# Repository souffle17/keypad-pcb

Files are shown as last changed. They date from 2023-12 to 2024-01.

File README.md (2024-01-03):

# keypad-pcb      

A simple 2x3 mechanical keypad.       

Case parts are designed for CNC machining, stacked and screwed together. Firmware uses QMK.       

### Resources:
- https://guide.zykrah.me/
- https://www.masterzen.fr/2020/05/03/designing-a-keyboard-part-1/
- https://wiki.ai03.com/books/pcb-design/chapter/pcb-designer-guide

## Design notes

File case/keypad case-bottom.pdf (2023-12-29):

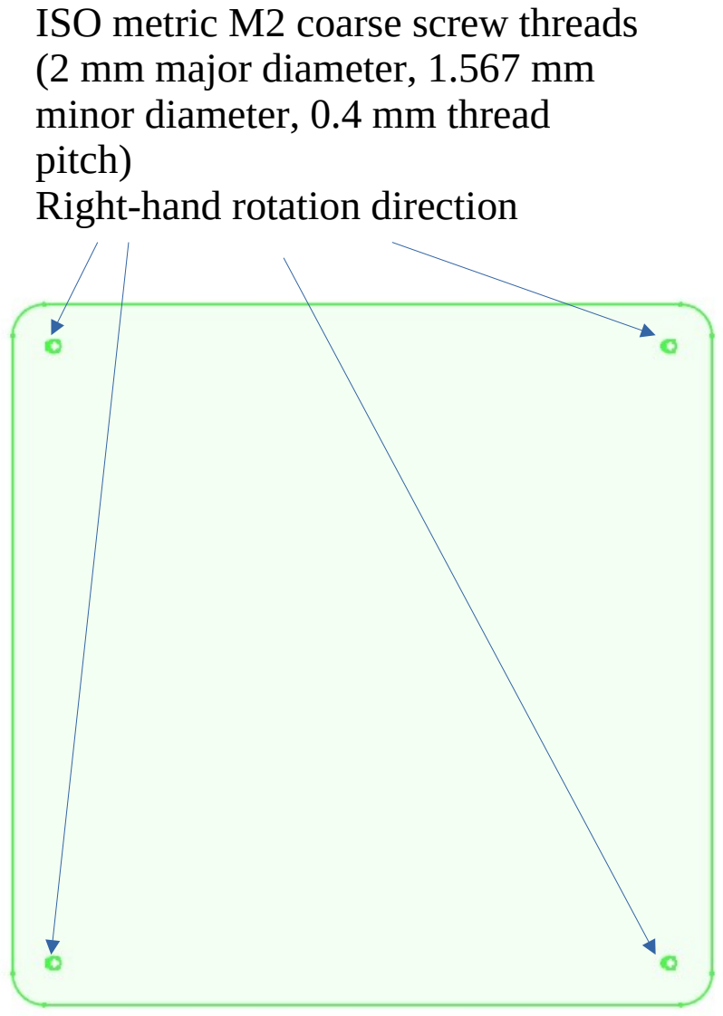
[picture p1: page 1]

ISO metric M2 coarse screw threads (2 mm major diameter, 1.567 mm minor diameter, 0.4 mm thread pitch)
Right-hand rotation direction

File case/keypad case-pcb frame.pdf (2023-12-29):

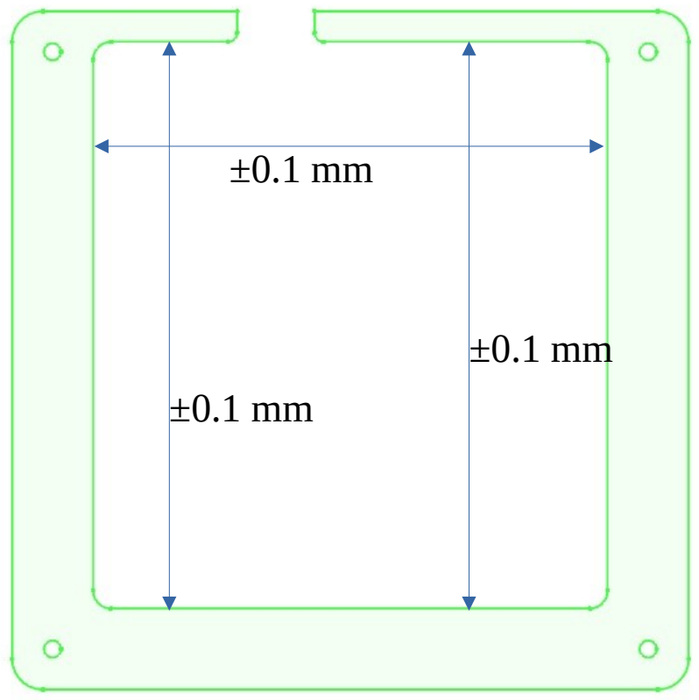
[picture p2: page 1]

±0.1 mm

±0.1 mm

±0.1 mm

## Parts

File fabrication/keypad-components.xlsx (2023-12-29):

Comment | Designator | Footprint | JLCPCB Part #（optional）
D | D5,D2,D6,D4,D3,D7 | SOD-123 | C77978
5.1k | R7,R8 | 0805 | C84375
ATmega32U4-A | U1 | TQFP-44 | C44854
RESET | SW0 | SKQG | C115351
10k | R4,R1 | 0805 | C84376
HRO-TYPE-C-31-M-12 | USB1 | HRO-TYPE-C-31-M-12 | C165948
0.1u | C2,C3,C4 | 0805 | C1711
1u | C1 | 0805 | C116352
22p | C6,C7 | 0805 | C1804
22 | R2,R3 | 0805 | C844832
PRTR5V0U2X | D1 | SOT143B | C12333
10u | C5 | 0805 | C95841
500m | F1 | 1206 | C70069
XTAL | Y1 | 3225 | C255909

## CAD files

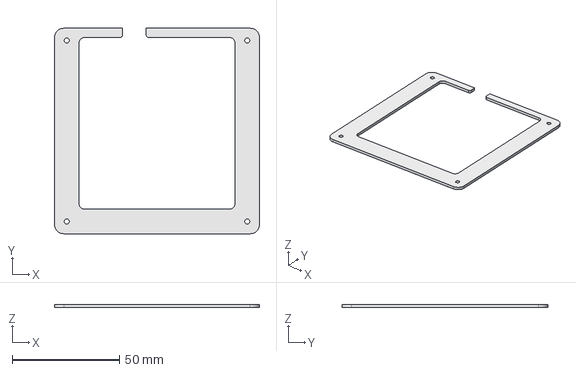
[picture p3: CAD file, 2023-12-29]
case/keypad case-pcb frame.step
95.5 x 95.7 x 1.60 mm

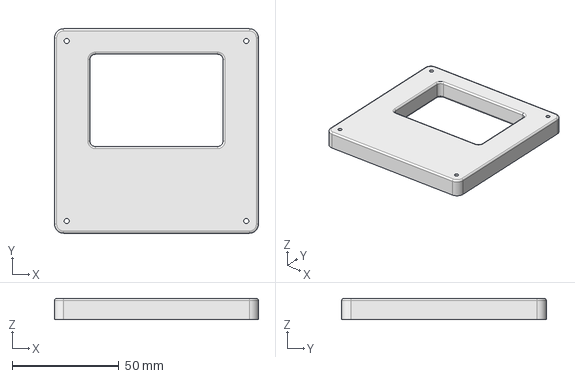
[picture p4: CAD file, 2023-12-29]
case/keypad case-top cover.step
95.5 x 95.7 x 10.0 mm

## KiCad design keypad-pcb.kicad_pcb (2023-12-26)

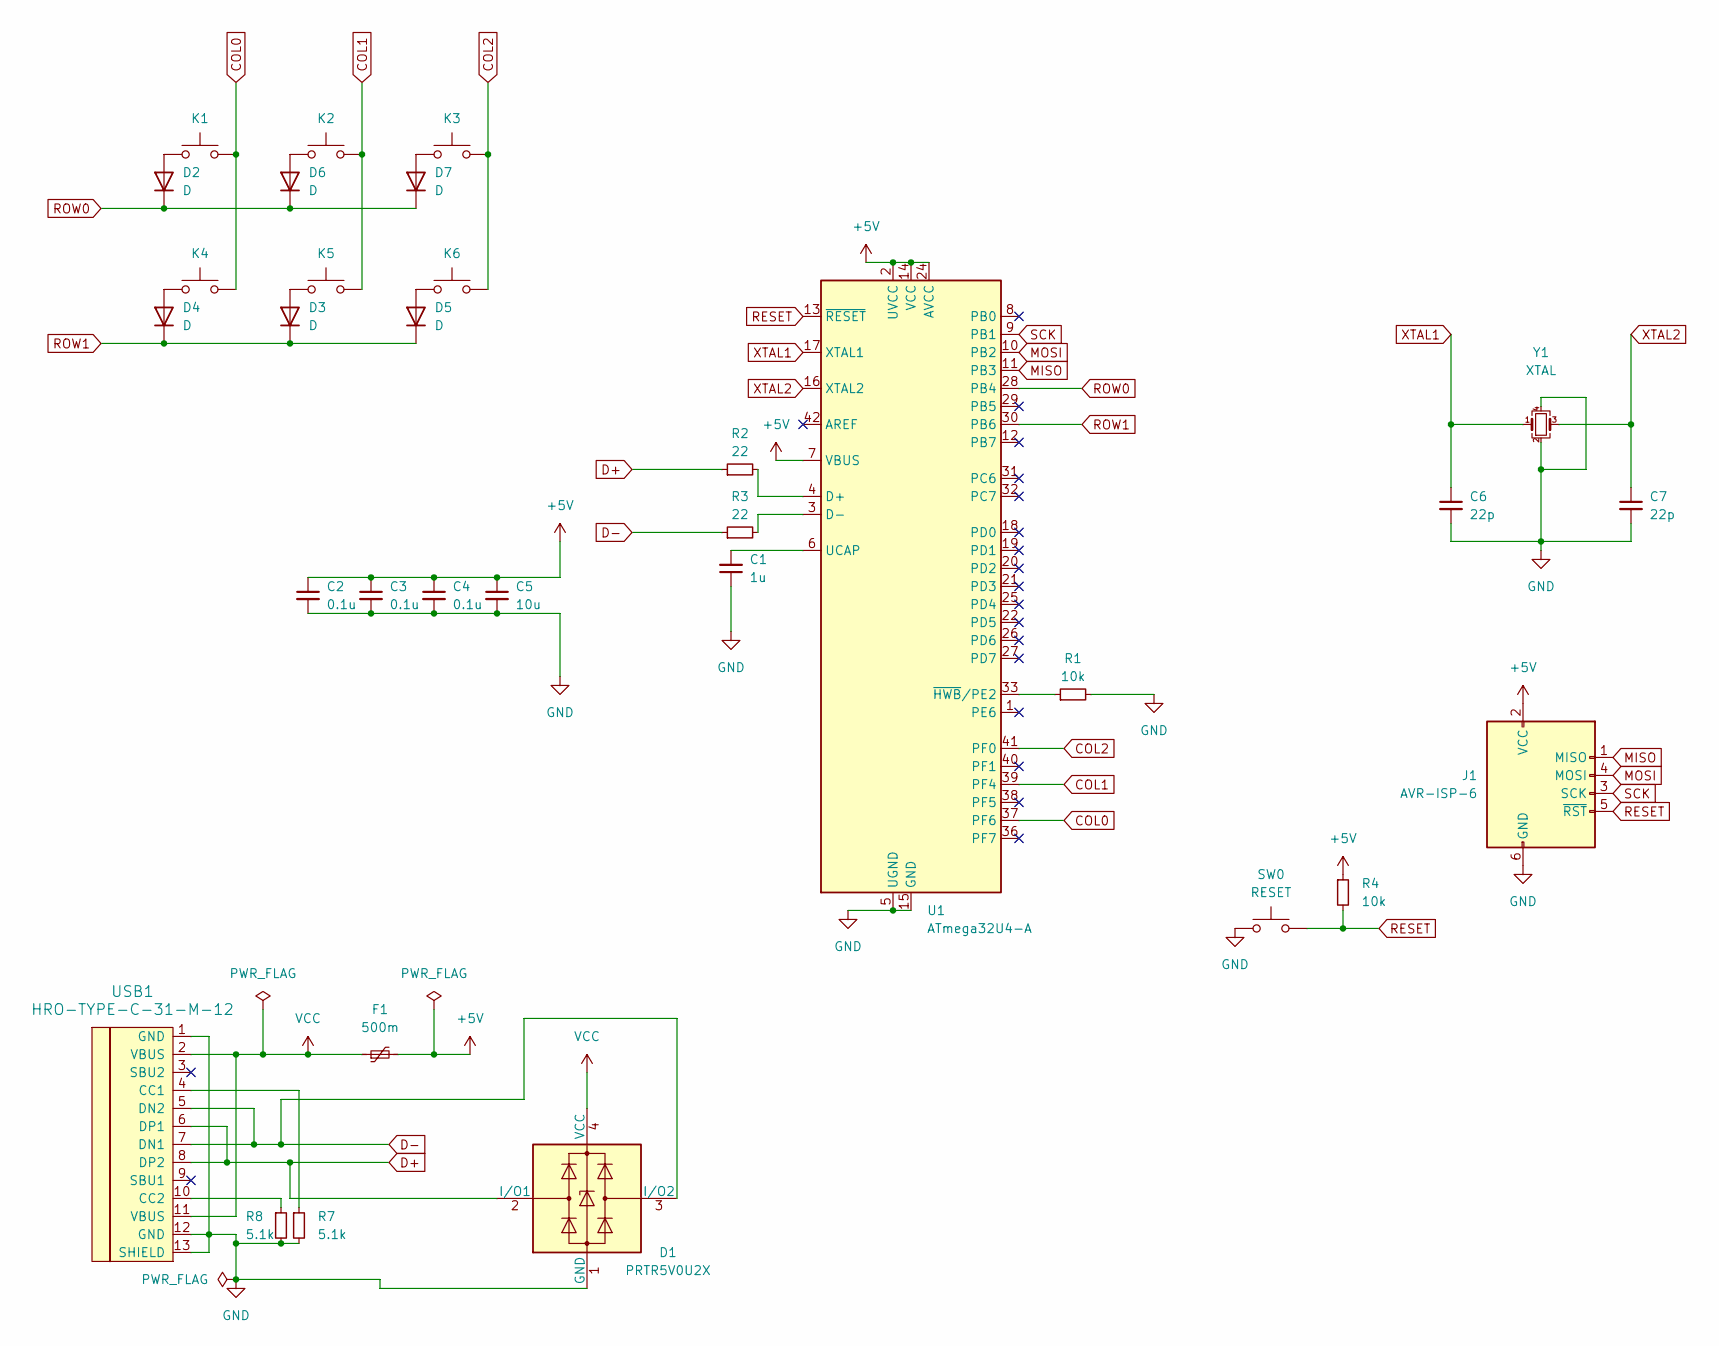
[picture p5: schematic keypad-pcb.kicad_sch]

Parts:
C1: 1u; C_0805_2012Metric
C2, C3, C4: 0.1u; C_0805_2012Metric
C5: 10u; C_0805_2012Metric
C6, C7: 22p; C_0805_2012Metric
D1: PRTR5V0U2X; SOT143B
D2, D3, D4, D5, D6, D7: D; D_SOD-123
F1: 500m; Fuse_1206_3216Metric
J1: AVR-ISP-6; Reset_Pretty-Mask
K1, K2, K3, K4, K5, K6: SW_Push; SW_MX_HS_1u
R1, R4: 10k; R_0805_2012Metric
R2, R3: 22; R_0805_2012Metric
R7, R8: 5.1k; R_0805_2012Metric
SW0: RESET; SW_SPST_SKQG_WithStem
U1: ATmega32U4-A; TQFP-44_10x10mm_P0.8mm
USB1: HRO-TYPE-C-31-M-12
Y1: XTAL; Crystal_SMD_3225-4Pin_3.2x2.5mm

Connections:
+5V: C2.1, C3.1, C4.1, C5.1, F1.2, J1.2 (VCC), R4.1, U1.2 (UVCC), U1.7 (VBUS), U1.14 (VCC), U1.24 (AVCC), U1.34 (VCC), U1.44 (AVCC)
COL0: K1.2, K4.2, U1.37 (PF6)
COL1: K2.2, K5.2, U1.39 (PF4)
COL2: K3.2, K6.2, U1.41 (PF0)
D+: D1.2 (I/O1), R2.1, USB1.6 (DP1), USB1.8 (DP2)
D-: D1.3 (I/O2), R3.1, USB1.5 (DN2), USB1.7 (DN1)
GND: C1.1, C2.2, C3.2, C4.2, C5.2, C6.2, C7.2, D1.1 (GND), J1.6 (GND), R1.2, R7.2, R8.2, SW0.1, U1.5 (UGND), U1.15 (GND), U1.23 (GND), U1.35 (GND), U1.43 (GND), USB1.1 (GND), USB1.12 (GND), USB1.13 (SHIELD), Y1.2, Y1.4
MISO: J1.1 (MISO), U1.11 (PB3)
MOSI: J1.4 (MOSI), U1.10 (PB2)
unnamed: D2.2 (A), K1.1
unnamed: D3.2 (A), K5.1
unnamed: D4.2 (A), K4.1
unnamed: D5.2 (A), K6.1
unnamed: D6.2 (A), K2.1
unnamed: D7.2 (A), K3.1
unnamed: R2.2, U1.4 (D+)
unnamed: R3.2, U1.3 (D-)
unnamed: C1.2, U1.6 (UCAP)
unnamed: R1.1, U1.33 (~HWB/PE2)
unnamed: R7.1, USB1.4 (CC1)
unnamed: R8.1, USB1.10 (CC2)
RESET: J1.5 (~RST), R4.2, SW0.2, U1.13 (~RESET)
ROW0: D2.1 (K), D6.1 (K), D7.1 (K), U1.28 (PB4)
ROW1: D3.1 (K), D4.1 (K), D5.1 (K), U1.30 (PB6)
SCK: J1.3 (SCK), U1.9 (PB1)
VCC: D1.4 (VCC), F1.1, USB1.2 (VBUS), USB1.11 (VBUS)
XTAL1: C6.1, U1.17 (XTAL1), Y1.1
XTAL2: C7.1, U1.16 (XTAL2), Y1.3

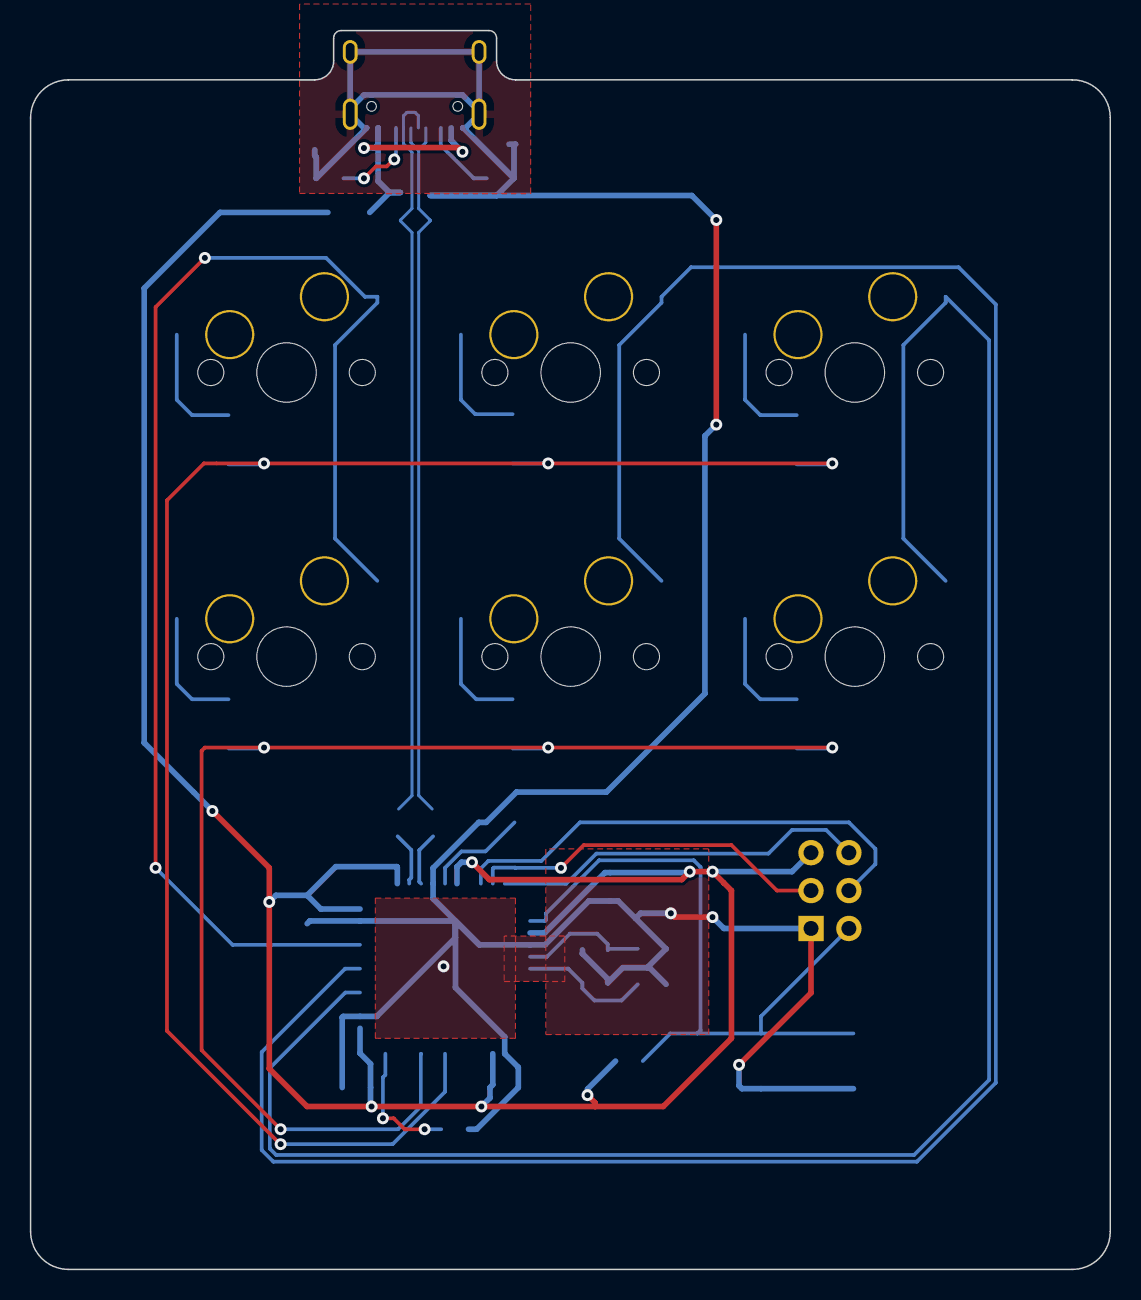
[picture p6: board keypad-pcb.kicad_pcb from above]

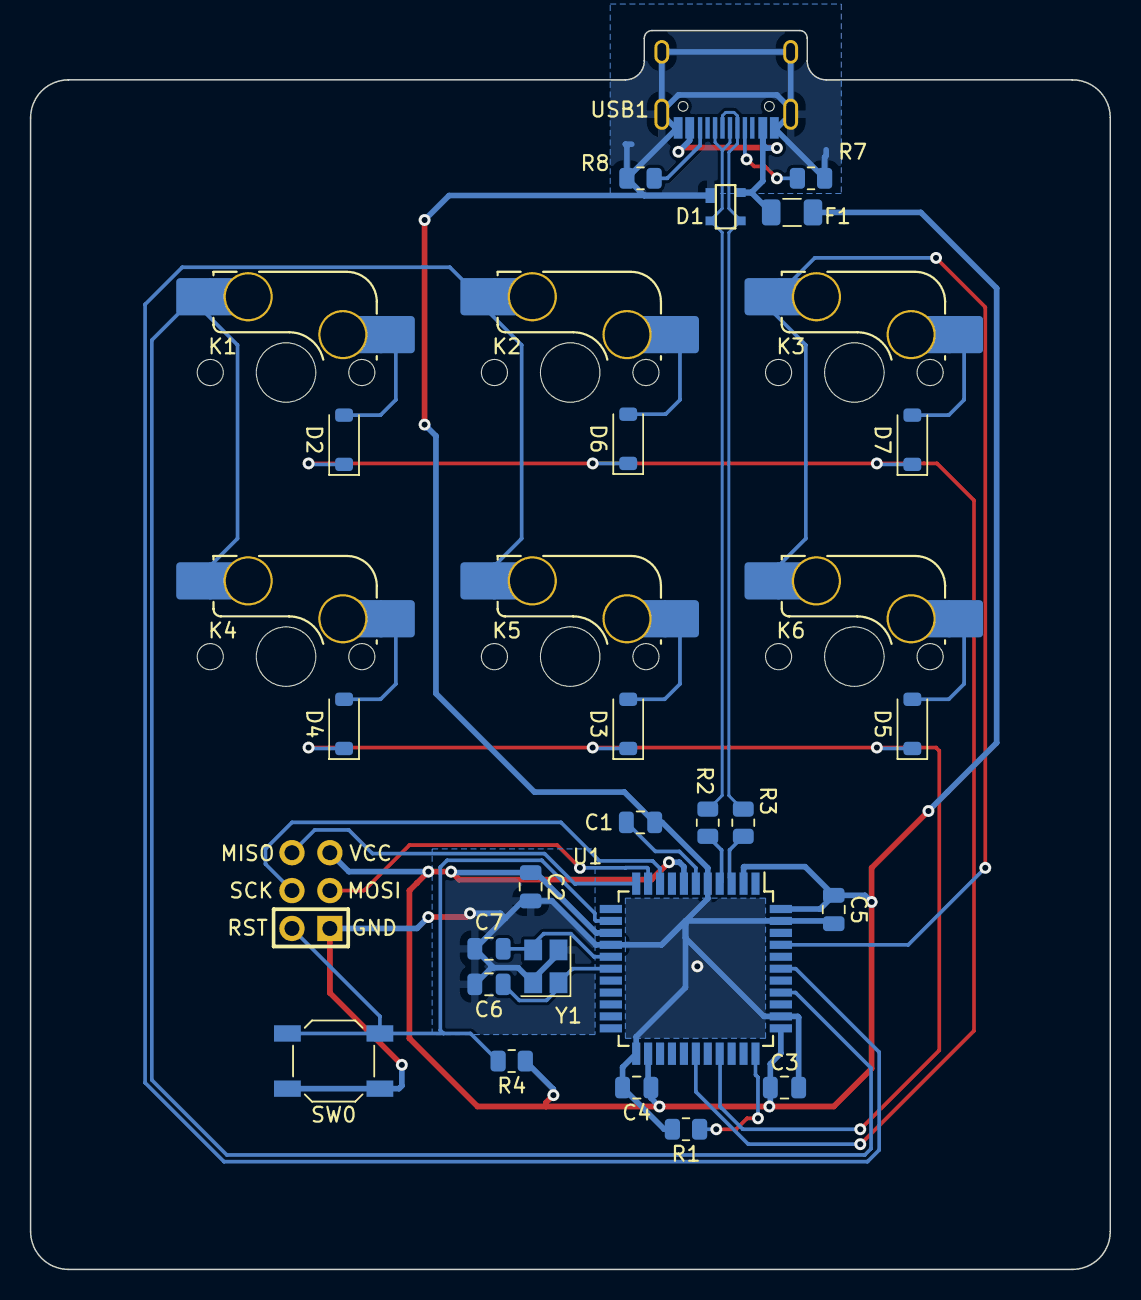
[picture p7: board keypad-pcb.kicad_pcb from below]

Board: 2 copper layers, 72.4 x 83.1 mm, 32 parts (32 on the bottom side), 28 nets.

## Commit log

2023-12-25 project files
    [keypad-pcb.kicad_pcb, keypad-pcb.kicad_sch]
2023-12-25 add modules, mcu, usb, debounce, reset, and clock
    [keypad-pcb.kicad_pcb, keypad-pcb.kicad_sch]
2023-12-25 esd protection
    [keypad-pcb.kicad_sch]
2023-12-25 mcu wiring
    [keypad-pcb.kicad_sch]
2023-12-25 power flag
    [keypad-pcb.kicad_sch]
2023-12-25 pcb start
2023-12-25 arrange parts
    [keypad-pcb.kicad_pcb, keypad-pcb.kicad_sch]
2023-12-25 some routing
    [keypad-pcb.kicad_pcb, keypad-pcb.kicad_sch]
2023-12-26 complete routing
    [keypad-pcb.kicad_pcb, keypad-pcb.kicad_sch]
2023-12-26 edge cut
    [keypad-pcb.kicad_pcb]
2023-12-26 smoothed corners
    [keypad-pcb.kicad_pcb]
2023-12-26 finish fills
    [keypad-pcb.kicad_pcb]
2023-12-26 missing ground
    [keypad-pcb.kicad_pcb]
2023-12-29 manufacturing files
    [keypad-components.xlsx, keypad-placements.xlsx]
